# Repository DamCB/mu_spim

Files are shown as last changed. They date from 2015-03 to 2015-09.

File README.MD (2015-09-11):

# This is the mu spim project -- welcome



Mu-spim implements **light sheet microscopy** on a
smartphone camera.

_Le Mu-spim est un microscope à **feuille de lumière** pour smartphone_

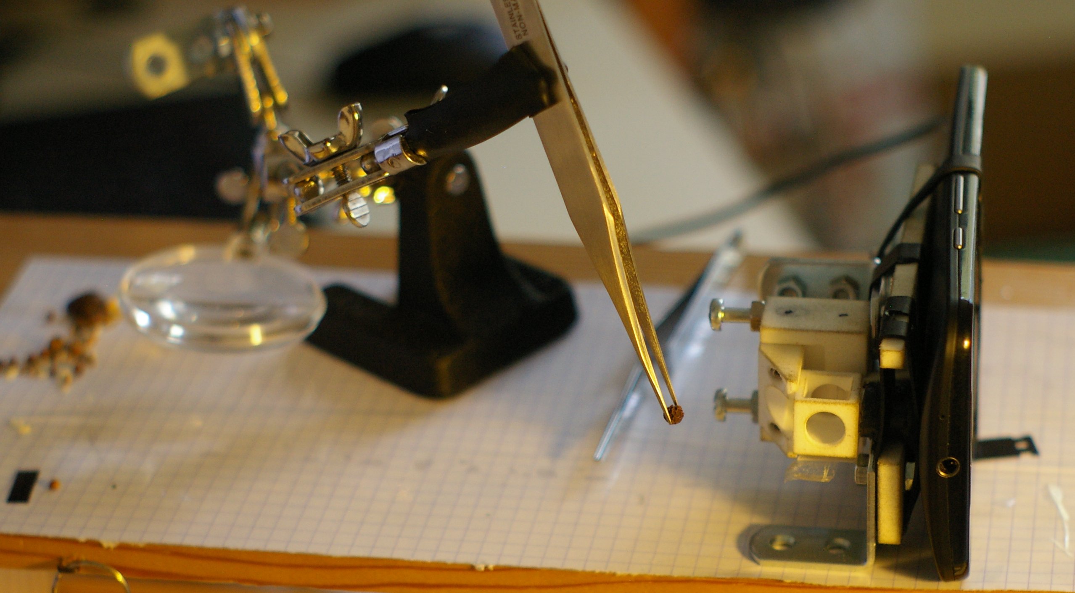
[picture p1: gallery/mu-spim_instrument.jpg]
The mu-spim v.0.1 - rubber
 

To take an image, one suspends the sample (here a grain of peper) in the small cubic room, in front of the telephone's objective.

_Pour prendre une image, on suspend l'échantillon (ici un grain de poivre) dans
la petite chambre cubique, devant l'objectif du téléphone_

The microscope uses the phone's LED flash to illuminate the sample, and a **cylindrical lens** creates a light-sheet. A section of the flat light field can be seen on the next image:

_Le microscope utilise la LED du téléphone pour illuminer un échantillon, et **une lentille cylindrique** créé une feuille de lumière. On voit ce champ lumineux par la tranche sur l'image suivante_

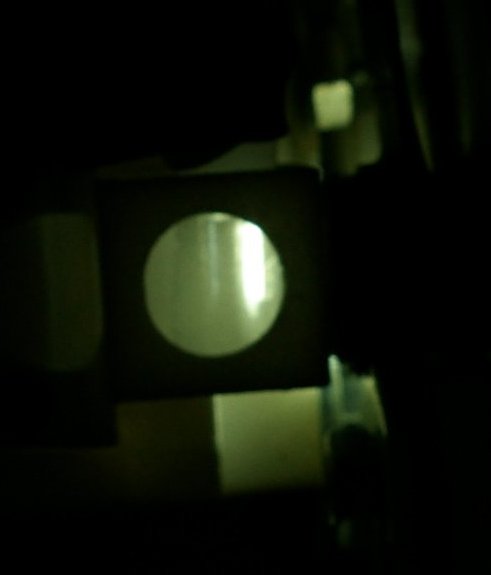
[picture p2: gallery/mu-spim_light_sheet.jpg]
The mu-spim v.0.1 - rubber


<hr/>

### La graîne de coriandre...

#### Avec la feuille de lumière (qui éclaire depuis la gauche)

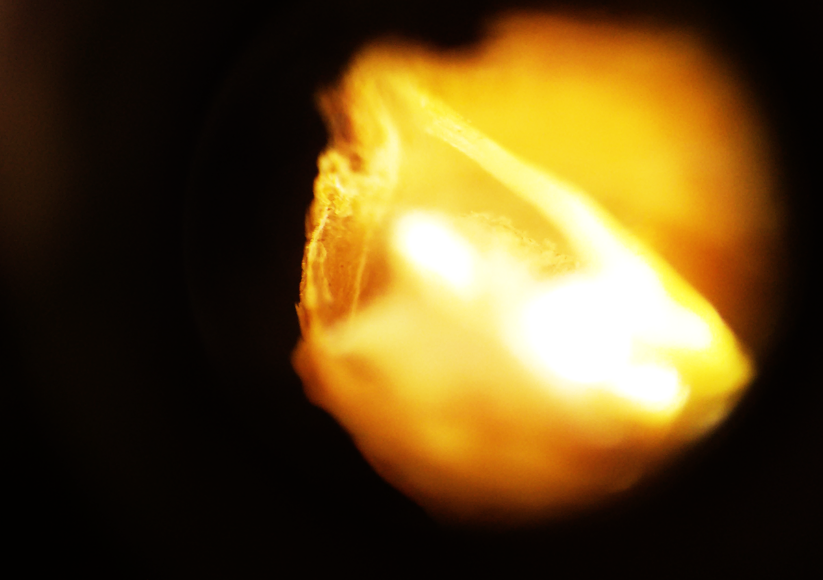
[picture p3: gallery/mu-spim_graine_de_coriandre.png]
The mu-spim v.0.1 - rubber


#### Sans la feuille de lumière

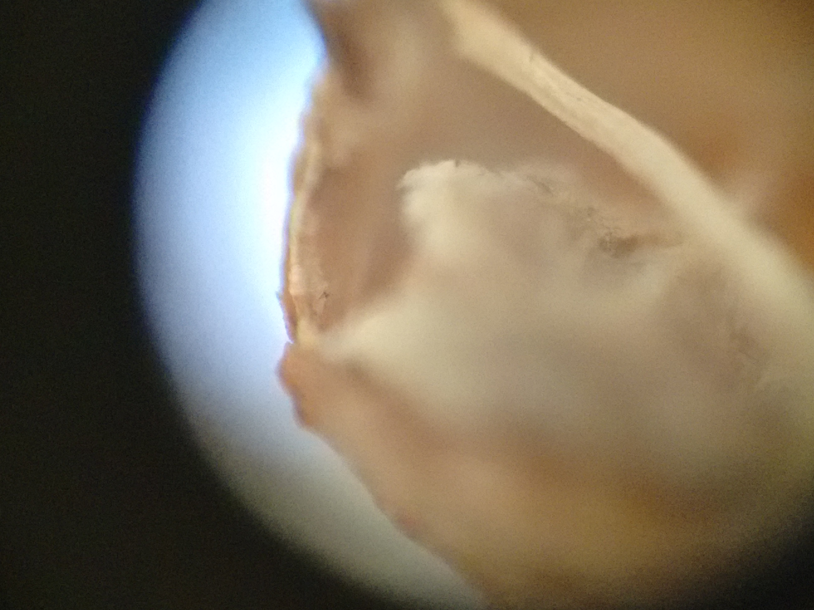
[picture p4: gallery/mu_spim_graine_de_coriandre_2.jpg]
The mu-spim v.0.1 - rubber


### Videos

<iframe src="https://player.vimeo.com/video/138321561" width="500" height="281" frameborder="0" webkitallowfullscreen mozallowfullscreen allowfullscreen></iframe> <p><a href="https://vimeo.com/138321561">Fleur s&ecirc;ch&eacute;e // Microscopy image of a flower stem. #mu-spim</a> from <a href="https://vimeo.com/user12210065">glyg</a> on <a href="https://vimeo.com">Vimeo</a>.</p>

<iframe src="https://player.vimeo.com/video/138322430" width="500" height="281" frameborder="0" webkitallowfullscreen mozallowfullscreen allowfullscreen></iframe> <p><a href="https://vimeo.com/138322430">Cardamome #mu-spim</a> from <a href="https://vimeo.com/user12210065">glyg</a> on <a href="https://vimeo.com">Vimeo</a>.</p>

> This is an early project under heavy development
>
> Guillaume Gay - http://damcb.com - guillaume@damcb.com

<br /><span xmlns:dct="http://purl.org/dc/terms/" property="dct:title">Mu-SPIM</span> de <a xmlns:cc="http://creativecommons.org/ns#" href="http://damcb.com" property="cc:attributionName" rel="cc:attributionURL">Guillaume Gay</a> est mis à disposition selon les termes de la <a rel="license" href="http://creativecommons.org/licenses/by-nc-sa/4.0/">licence Creative Commons Attribution - Pas d’Utilisation Commerciale - Partage dans les Mêmes Conditions 4.0 International</a>.<br />Fondé(e) sur une œuvre à <a xmlns:dct="http://purl.org/dc/terms/" href="https://github.com/glyg/mu_spim" rel="dct:source">https://github.com/glyg/mu_spim</a>.

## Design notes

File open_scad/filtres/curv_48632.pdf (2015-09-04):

## B-440 UV-VIS Bandpass Filter Coating Performance FOR REFERENCE ONLY

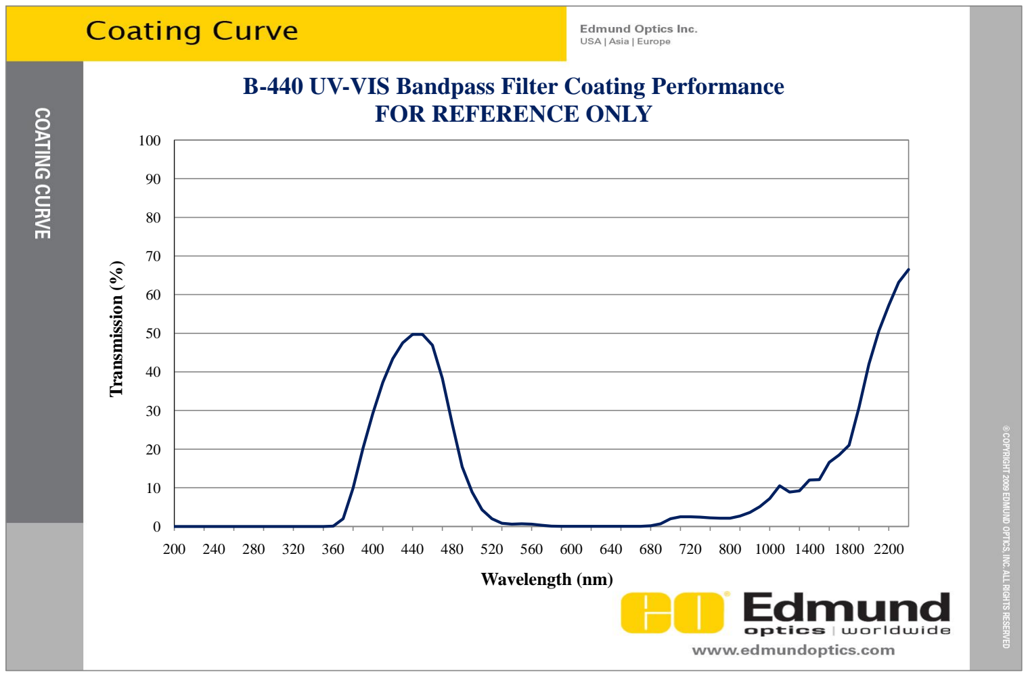
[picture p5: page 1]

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
200 | 240 | 280 | 320 | 360 | 400 | 440 | 480 | 520 | 560 | 600 | 640 | 680 | 720 | 800 1000 1400 1800 2200

### Transmission (%)

Wavelength (nm)

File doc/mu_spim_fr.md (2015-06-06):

# Mu-spim
### Un microscope 3D pour smartphone

## Introduction

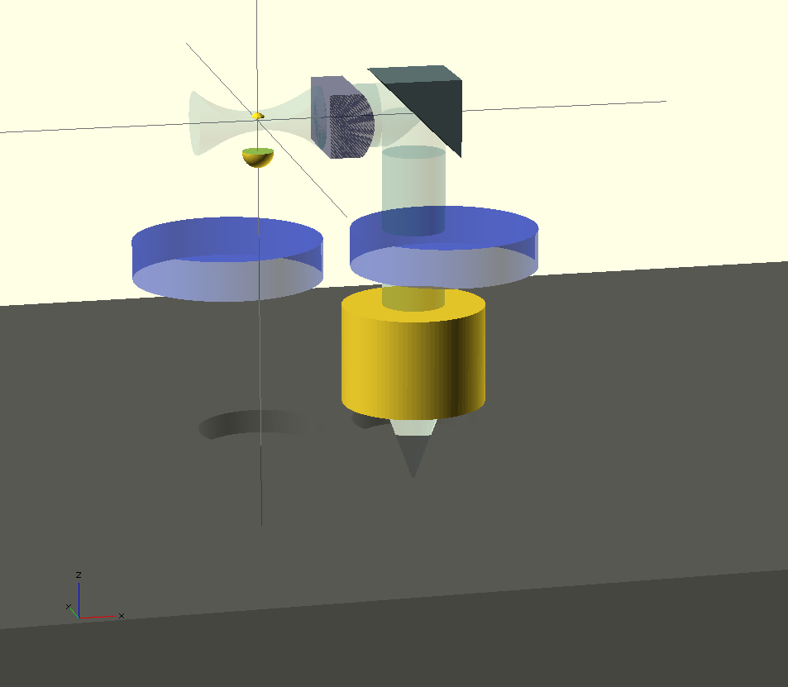
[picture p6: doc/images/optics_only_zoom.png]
Une petite feuille de lumière


Mon premier appareil photo était un petit compact Olympius, le µ-one,
offert pour mes quatorze ans. Il tenait dans la pomme de la main,
avait un zoom réglable et faisait des belles photos - sur pellicule,
au risque de trahir mon âge.

Le mu-spim aussi tient dans le creux de la main et permet de fixer le
monde qui nous entoure. L'échelle est bien différente de mon petit
appareil compact, cependant: on regarde du petit, du minuscule, plus
petit que le millimètre. Le mu-spim est un microscope portable qui
s'attache à un smartphone. En faisant tourner l'échantillon devant
l'objectif, on l'observe sous toutes ses facettes et on peut en faire
une reconstruction en trois dimensions.

Ce microscope s'inspire de deux instruments existants: le premier est
le SPIM (_Selective Plane Illumination Microscope_, microscope à plan
d'illumination sélectif), un microscope à feuille de lumière (on va y
revenir!), à destination des chercheurs en biologie. C'est un appareil
de laboratoire, équipé d'une caméra hyper-sensible et de lasers pour
éclairer les échantillons. Il y a quelques années, avec Corinne
Lorenzo et Valérie Lobjois, nous avons construit un microscope de ce
type à Toulouse. Il existe une version ouverte de ce type de
microscope: [l'OpenSPIM](http://openspim.org), que l'on peut assembler
soi même, si l'on dispose d'un bon atelier d'optique.

La deuxième source d'inspiration est le merveilleux
[Foldscope](http://foldscope.org) développé à Stanford dans le
laboratoire de Manu Parkash. C'est un petit microscope en papier, que
l'on peut tenir devant ses yeux ou devant l'objectif d'un
téléphone. Il ne coûte presque rien à fabriquer et peut être employé
dans tous les terrains, par exemple pour diagnostiquer rapidement une
infection virale dans un échantillon sanguin.

Dans la tradition du développement ouvert, le Mu-Spim est un _mix_ de
ces deux outils.

Ce projet s'adresse à deux publics, principalement:

* Les amateurs, curieux et les structures de vulgarisation
  scientifique.

* Les professionnels qui auraient besoin d'un microscope précis et
  transportable pour le diagnostic micro-biologique (bilan écologique, piscines).

##

## La microscopie à feuille de lumière

L'idée de base de ce type de microscope est de produire une _feuille
de lumière_ pour éclairer un échantillon par la tranche.

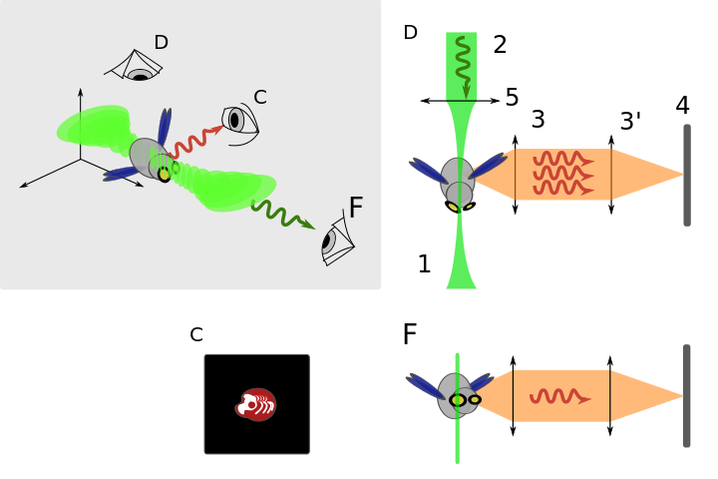
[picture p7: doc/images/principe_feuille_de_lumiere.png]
principe de la microscopie de feuille de lumière


En acquérant successivement plusieurs tranches de l'échantillon, on
parvient à reconstruire une vue en trois dimensions de ce dernier.

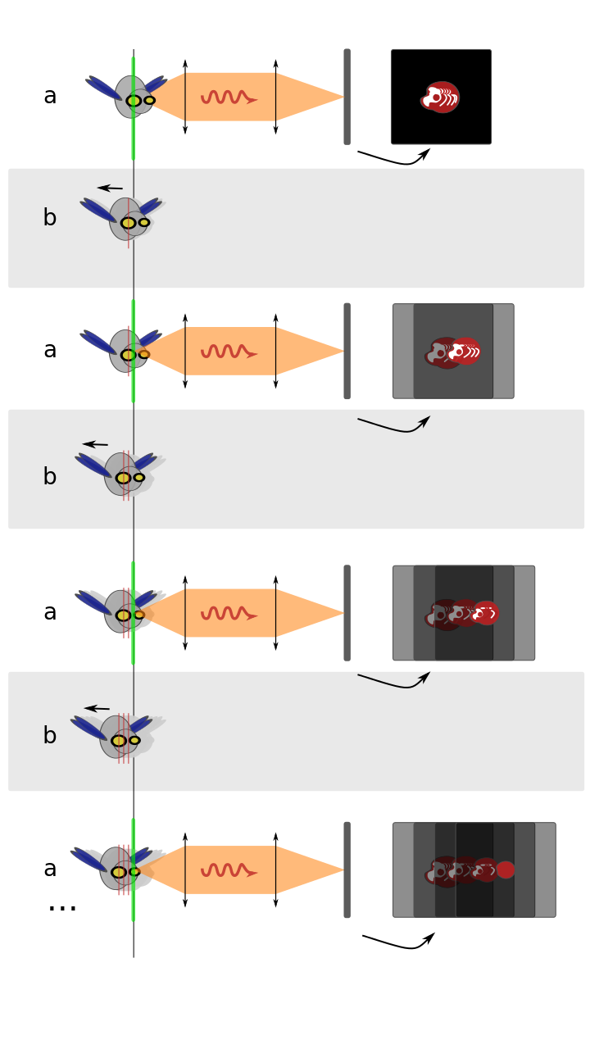
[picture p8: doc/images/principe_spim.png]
reconstruction 3D


Cette méthode de microscopie a été redécouverte par le groupe de Enrst
Stelzer au milieu des années 2000.

L'objectif est avant tout **éducatif**: rendre visible le monde
foisonnant et étrange du plus-petit-que-le-cheveu.

Ce projet s'inscrit dans une démarche **ouverte**: le code et les plans
de l'objet seront distribués sous licence libre (CC-by-SA, comme le
projet parent).

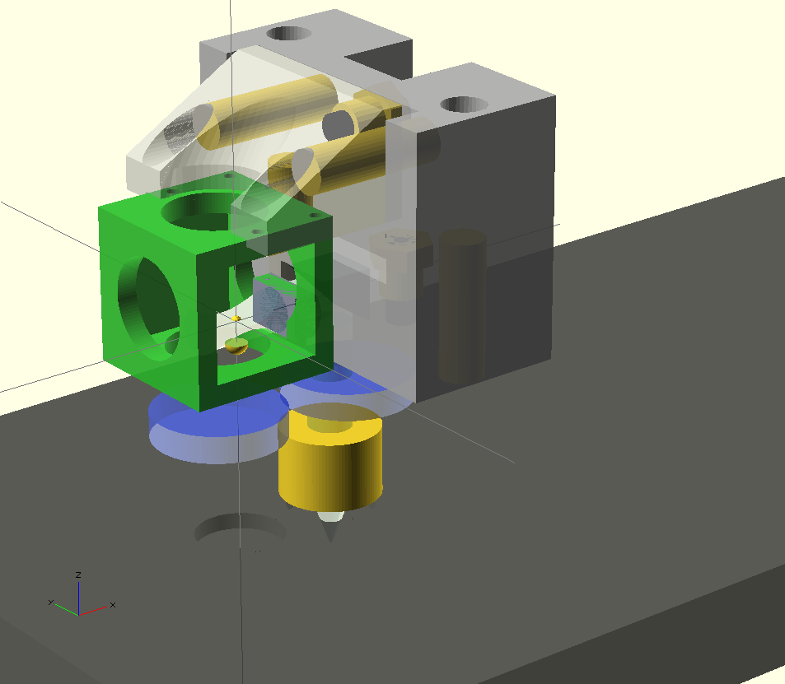
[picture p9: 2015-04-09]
doc/images/optics+chamber+top+colim.png

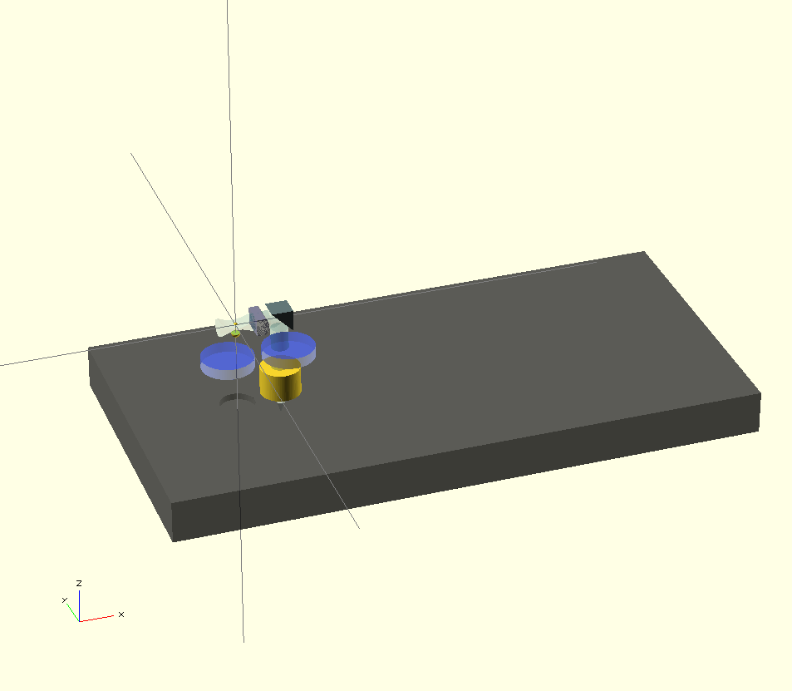
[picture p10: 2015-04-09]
doc/images/optics_only.png

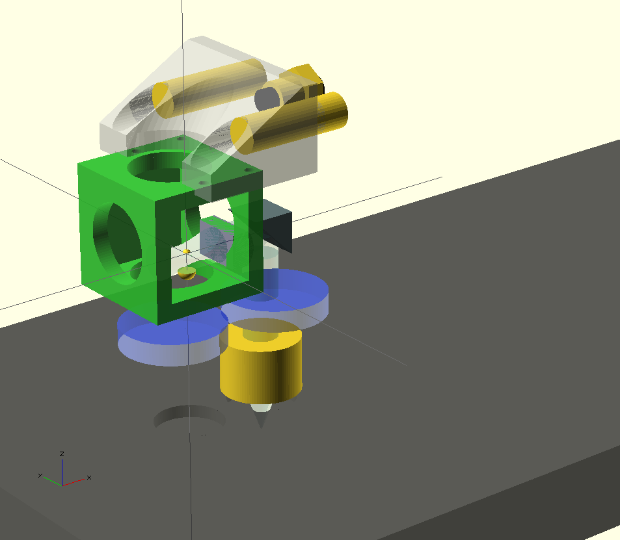
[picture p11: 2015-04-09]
doc/images/optics+chamber+top.png

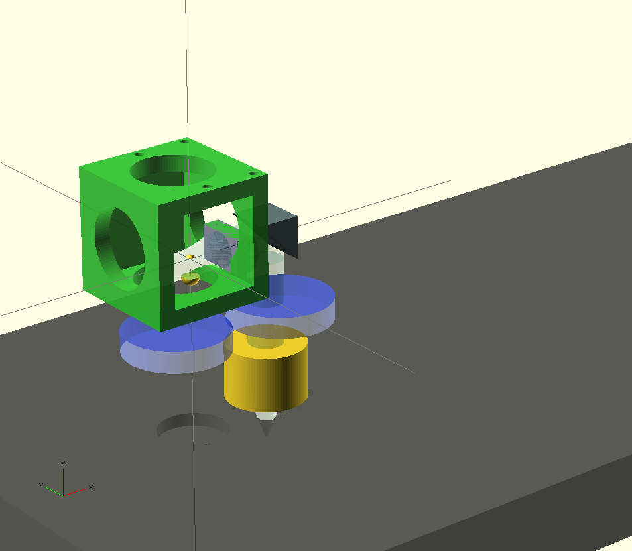
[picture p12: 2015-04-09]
doc/images/optics+chamber.png

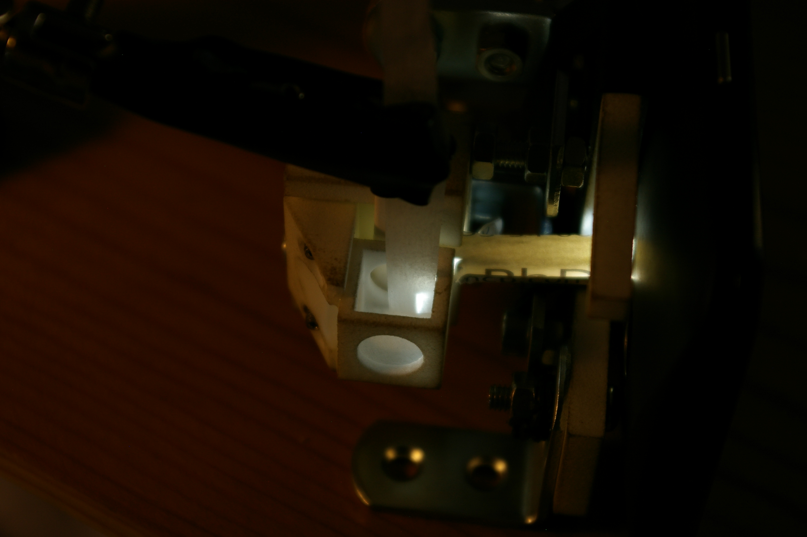
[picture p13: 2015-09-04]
doc/images/IMGP2792.JPG

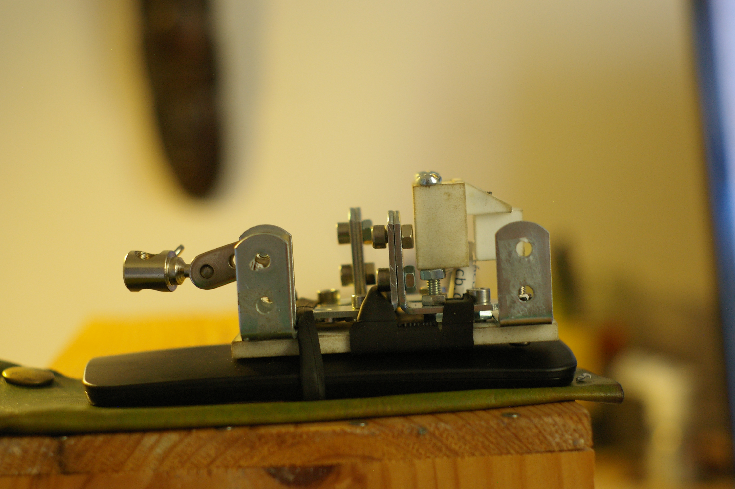
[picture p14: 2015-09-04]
doc/images/IMGP2789.JPG

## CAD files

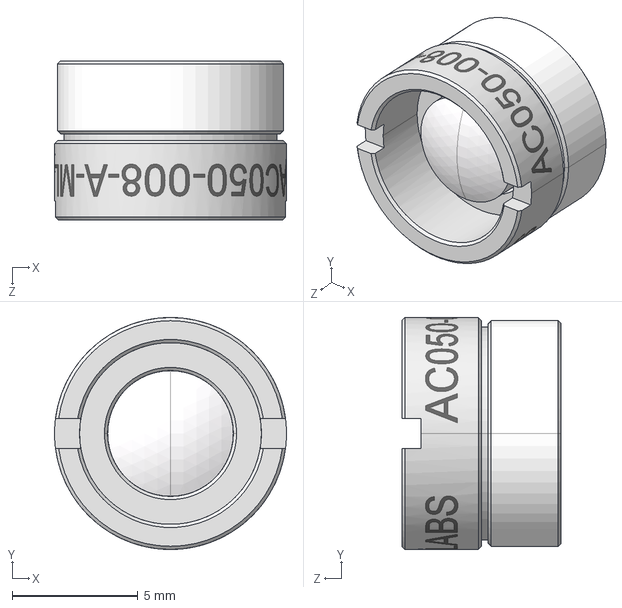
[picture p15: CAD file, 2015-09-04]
open_scad/parts/AC050-008-A-ML-Step.step
9.24 x 9.24 x 6.35 mm

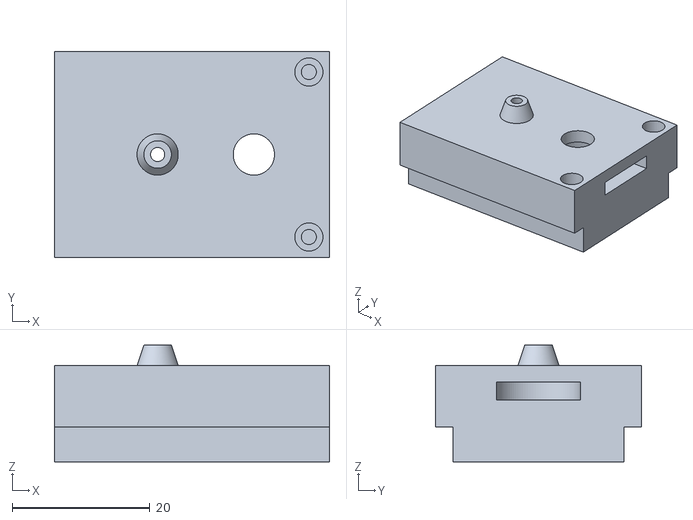
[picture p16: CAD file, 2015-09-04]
stl/base_block.stl
40.0 x 30.0 x 17.0

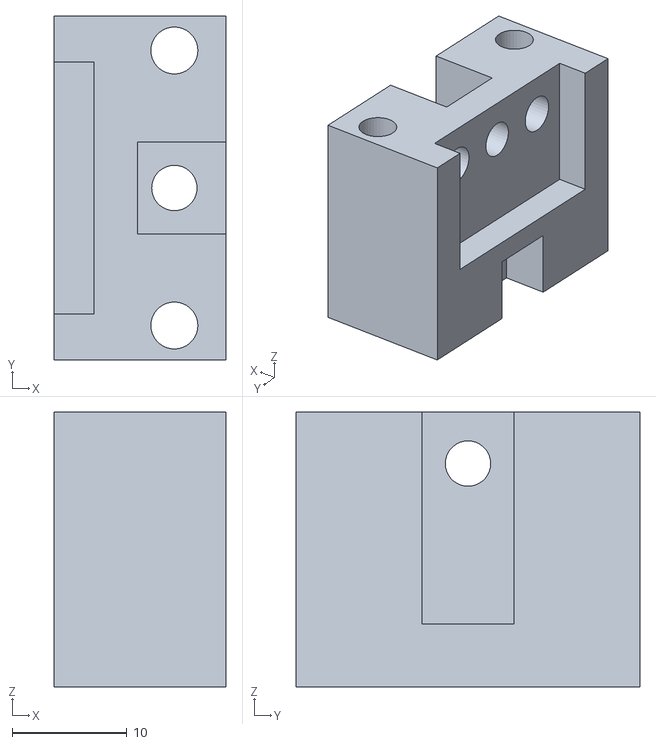
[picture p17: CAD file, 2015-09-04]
stl/collimation_block.stl
15.0 x 30.0 x 24.0

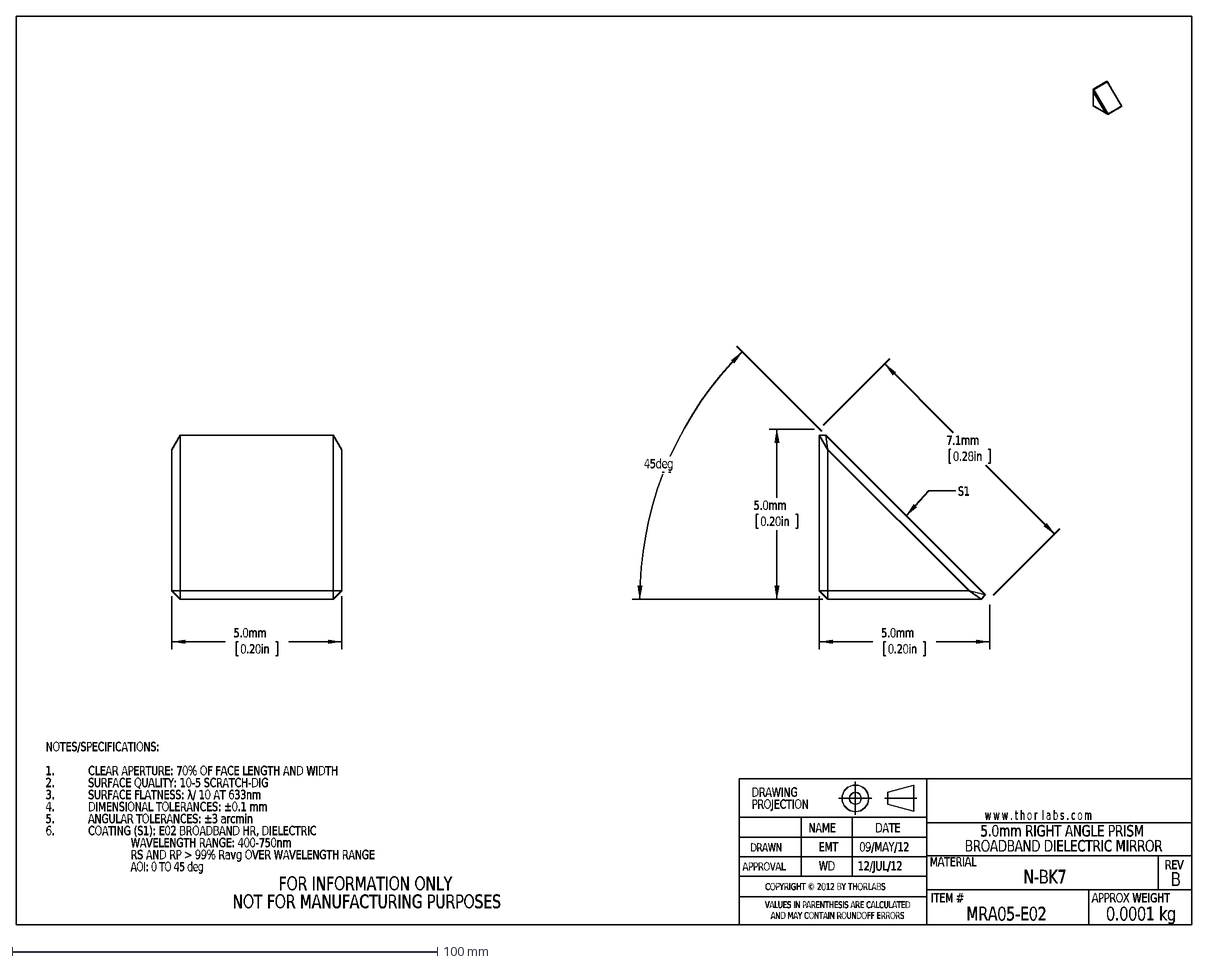
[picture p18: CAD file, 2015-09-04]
open_scad/parts/MRA05-E02-AutoCADDXF.dxf
NOTES/SPECIFICATIONS:
CLEAR APERTURE: 70% OF FACE LENGTH AND WIDTH
1.
SURFACE QUALITY: 10-5 SCRATCH-DIG
2.
SURFACE FLATNESS: λ/ 10 AT 633nm
3.
DIMENSIONAL TOLERANCES: ±0.1 mm
4.
ANGULAR TOLERANCES: ±3 arcmin
5.
COATING (S1): E02 BROADBAND HR, DIELECTRIC
6.
WAVELENGTH RANGE: 400-750nm
RS AND RP > 99% Ravg OVER WAVELENGTH RANGE
AOI: 0 TO 45 deg
B
MRA05-E02
MATERIAL
DRAWN
APPROVAL
REV
EMT
09/MAY/12
DATE
w w w . t h o r l a b s . c o m
ITEM #
APPROX WEIGHT
N-BK7
0.0001 kg
VALUES IN PARENTHESIS ARE CALCULATED
AND MAY CONTAIN ROUNDOFF ERRORS
DRAWING
PROJECTION
NAME
FOR INFORMATION ONLY
NOT FOR MANUFACTURING PURPOSES
5.0mm RIGHT ANGLE PRISM
BROADBAND DIELECTRIC MIRROR
COPYRIGHT © 2012 BY THORLABS
WD
12/JUL/12
5.0mm
0.20in
7.1mm
0.28in
45deg
S1

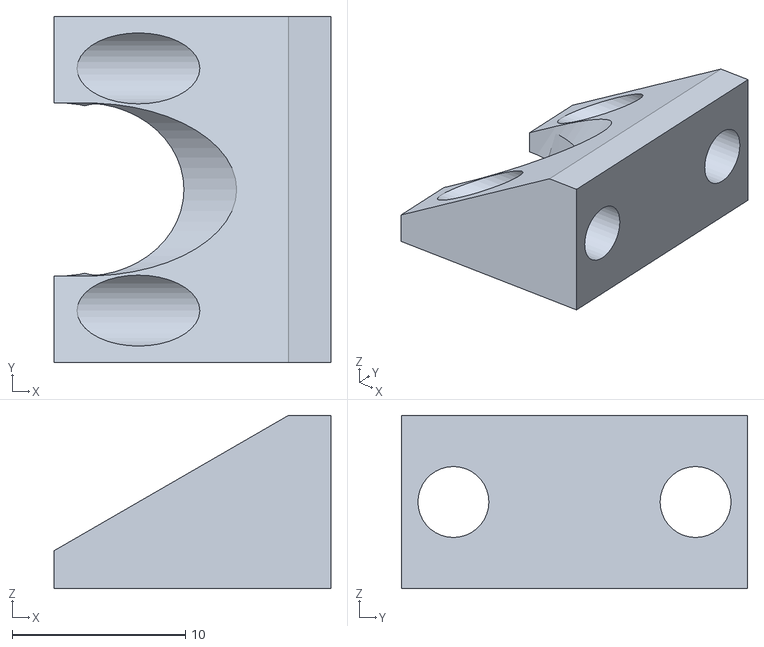
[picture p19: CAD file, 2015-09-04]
stl/chamber_top.stl
16.0 x 20.0 x 10.0

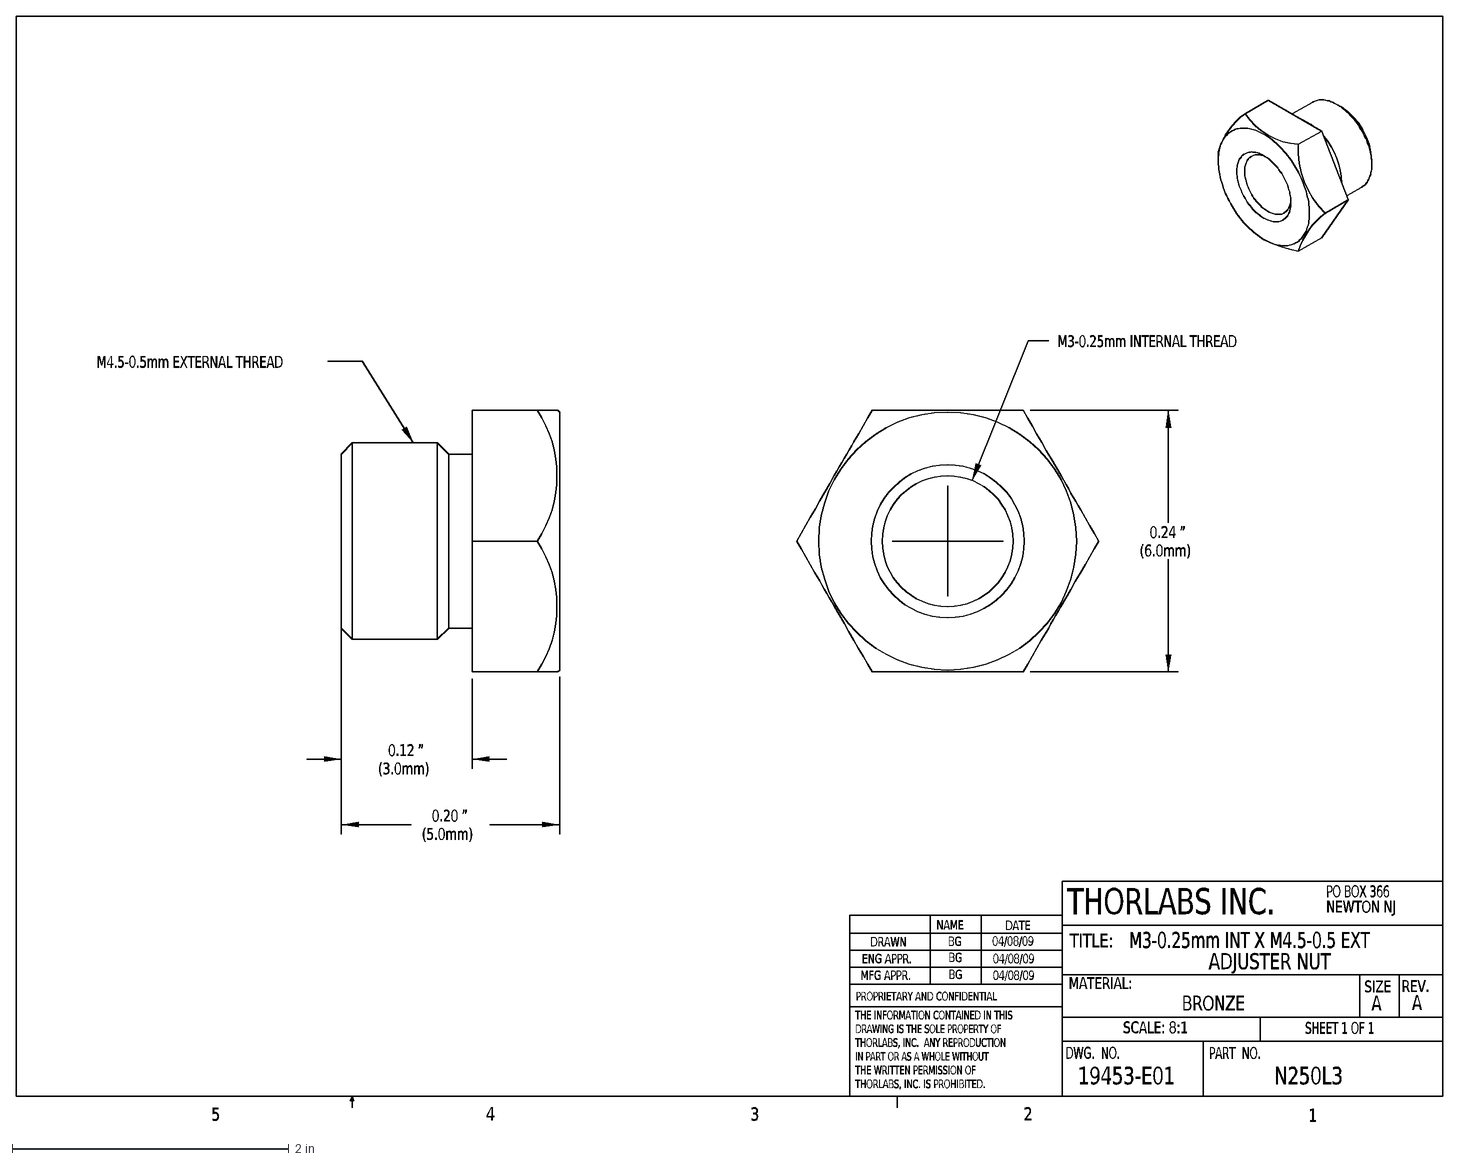
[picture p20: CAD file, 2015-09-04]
open_scad/parts/N250L3P-AutoCADDXF.dxf
A
5
4
3
2
1
N250L3
MATERIAL:
PART NO.
PROPRIETARY AND CONFIDENTIAL
DRAWN
ENG APPR.
MFG APPR.
NAME
TITLE:
SIZE
REV.
SCALE: 8:1
SHEET 1 OF 1
19453-E01
THE INFORMATION CONTAINED IN THIS
DRAWING IS THE SOLE PROPERTY OF
THORLABS, INC. ANY REPRODUCTION
IN PART OR AS A WHOLE WITHOUT
THE WRITTEN PERMISSION OF
THORLABS, INC. IS PROHIBITED.
DWG. NO.
BG
04/08/09
DATE
THORLABS INC.
PO BOX 366
NEWTON NJ
M3-0.25mm INT X M4.5-0.5 EXT
ADJUSTER NUT
BRONZE
0.24
”
(6.0mm)
M3-0.25mm INTERNAL THREAD
0.20
(5.0mm)
0.12
(3.0mm)
M4.5-0.5mm EXTERNAL THREAD

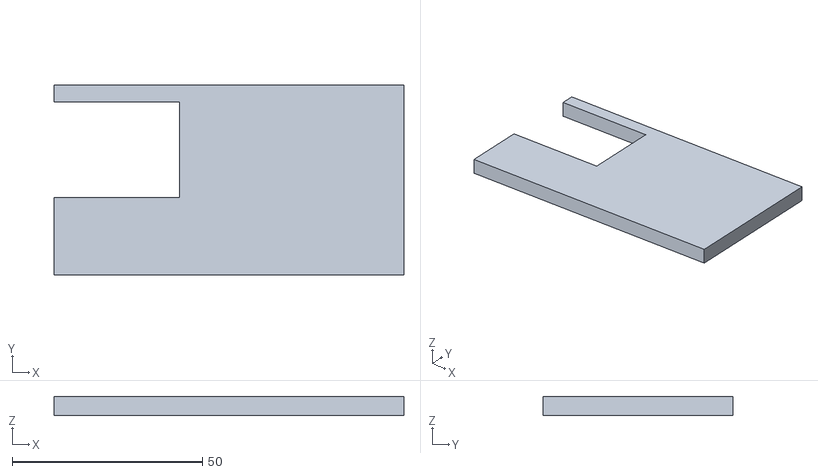
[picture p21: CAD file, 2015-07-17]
stl/optics_plate.stl
92.0 x 50.0 x 5.00

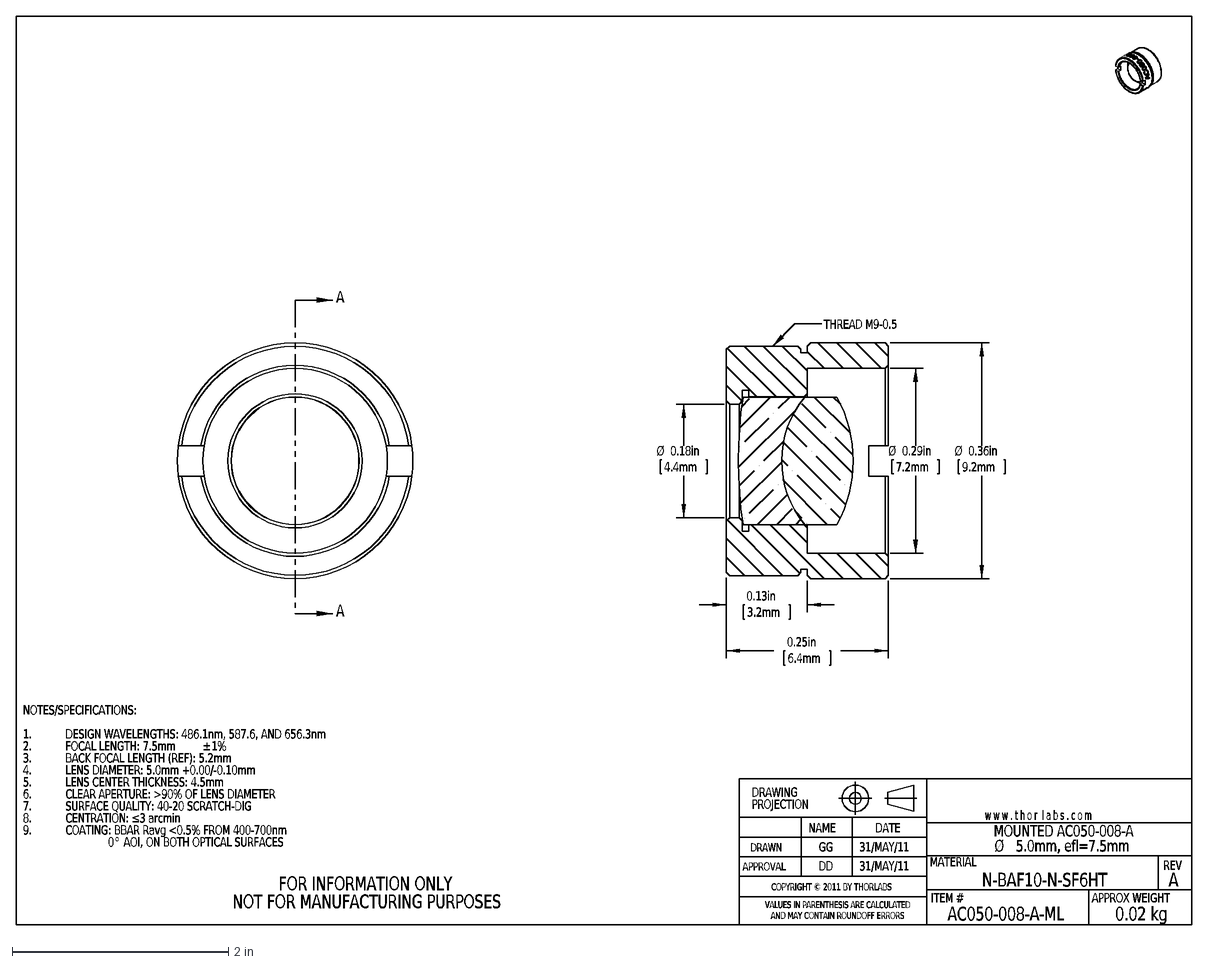
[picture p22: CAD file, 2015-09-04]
open_scad/parts/AC050-008-A-ML-AutoCADDXF.dxf
NOTES/SPECIFICATIONS:
DESIGN WAVELENGTHS: 486.1nm, 587.6, AND 656.3nm
1.
FOCAL LENGTH: 7.5mm
±
1%
2.
BACK FOCAL LENGTH (REF): 5.2mm
3.
LENS DIAMETER: 5.0mm +0.00/-0.10mm
4.
LENS CENTER THICKNESS: 4.5mm
5.
CLEAR APERTURE: >90% OF LENS DIAMETER
6.
SURFACE QUALITY: 40-20 SCRATCH-DIG
7.
CENTRATION: ≤3 arcmin
8.
COATING: BBAR Ravg <0.5% FROM 400-700nm
9.
0
°
AOI, ON BOTH OPTICAL SURFACES
A
AC050-008-A-ML
MATERIAL
DRAWN
APPROVAL
REV
GG
DD
31/MAY/11
DATE
w w w . t h o r l a b s . c o m
ITEM #
APPROX WEIGHT
N-BAF10-N-SF6HT
0.02 kg
VALUES IN PARENTHESIS ARE CALCULATED
AND MAY CONTAIN ROUNDOFF ERRORS
DRAWING
PROJECTION
NAME
FOR INFORMATION ONLY
NOT FOR MANUFACTURING PURPOSES
COPYRIGHT © 2011 BY THORLABS
MOUNTED AC050-008-A
Ø
5.0mm, efl=7.5mm
0.36in
9.2mm
0.25in
6.4mm
0.13in
3.2mm
0.18in
4.4mm
0.29in
7.2mm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

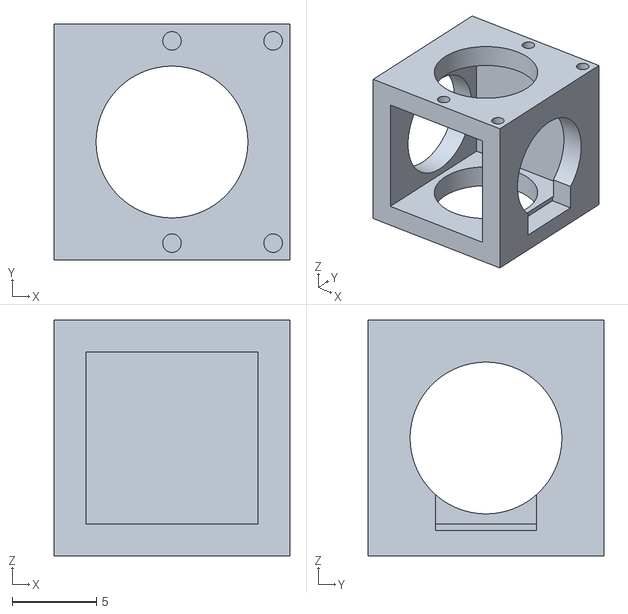
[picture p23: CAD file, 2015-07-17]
stl/chamber.stl
14.0 x 14.0 x 14.0

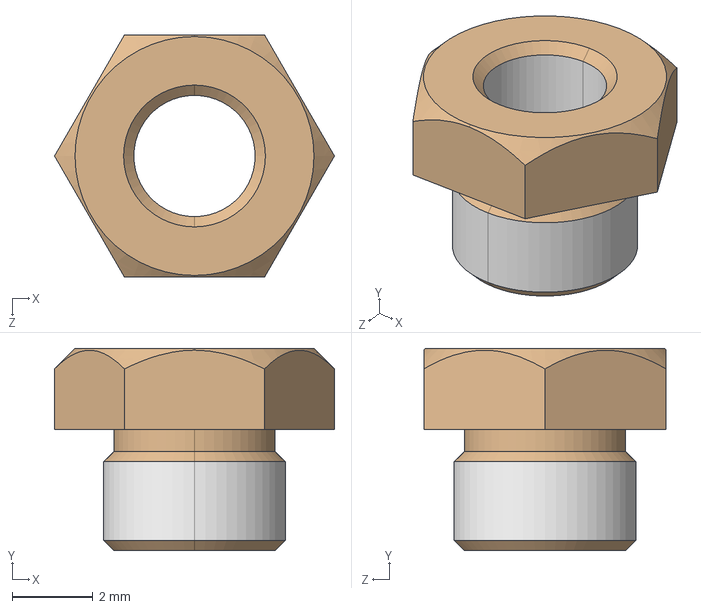
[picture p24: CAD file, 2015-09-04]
open_scad/parts/N250L3P-Step.step
6.93 x 5.00 x 6.00 mm

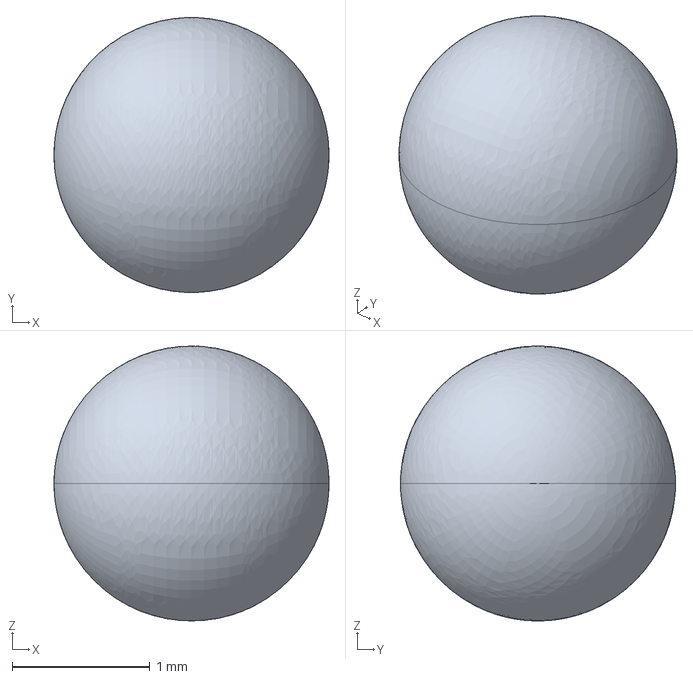
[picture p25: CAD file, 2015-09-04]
open_scad/parts/iges_32744.igs
2.00 x 2.00 x 2.00 mm

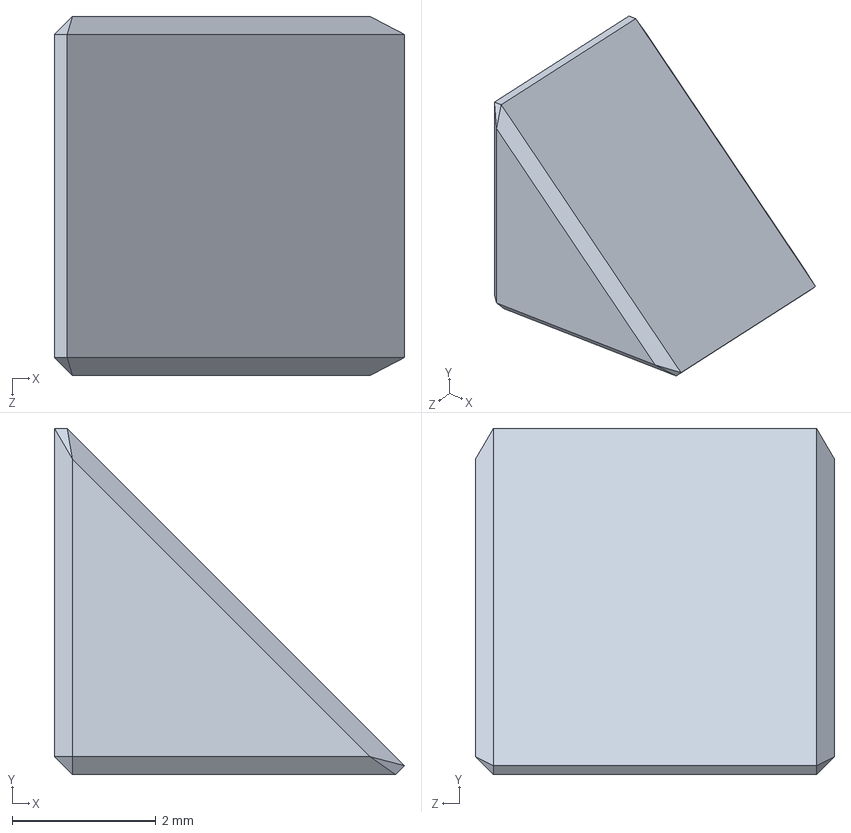
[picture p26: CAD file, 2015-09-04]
open_scad/parts/MRA05-E02-Step.step
4.88 x 4.82 x 5.00 mm

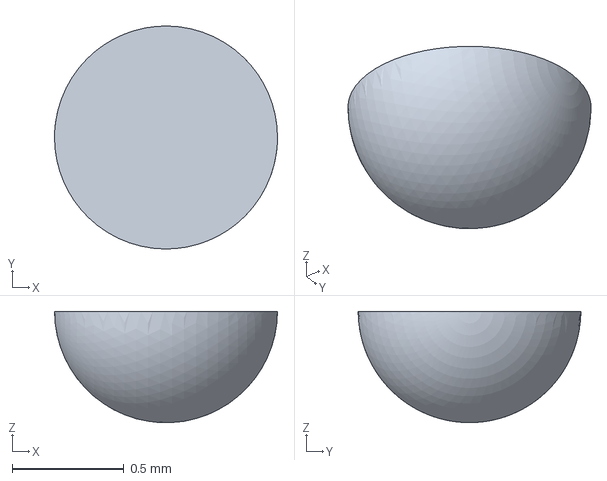
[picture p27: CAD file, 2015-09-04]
open_scad/parts/step_49568.stp
1.00 x 1 x 0.499 mm

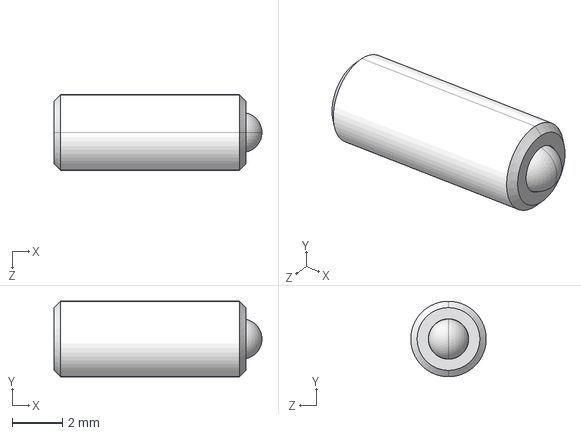
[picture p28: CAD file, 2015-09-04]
open_scad/parts/F3SS8-Step.step
8.25 x 3.00 x 3.00 mm

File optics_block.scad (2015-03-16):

use <chamber.scad>;
use <excitation_optics.scad>;
use <collection_optics.scad>;

use <libraries/thread.scad>;


module hex_adjustment_screw
(
    //THORLABS P/N F3SS8
)
{
    color([0, 0, 0])
    union()
    {
	difference()
	{
	    metric_thread(3, 0.25, 7.6);
	    translate([0, 0, -0.1]) cylinder(r=0.75, h=2.1, $fn=6);
	}
	translate([0, 0, 7.]) sphere(d=1.5, $fn=100);
    }
}

module adjuster_nut
(
    //THORLABS P/N N250L3
)
{
    difference()
    {
	union()
	{
	    cylinder(r=3, h=2, $fn=6);
	    translate([0, 0, 2]) metric_thread(4.5, 0.5, 3);
	}
	translate([0, 0, -1]) metric_thread(3, 0.25, 7.6, internal=true);
    }
}

module adjuster
(
    nut_shift=1.2
)
{
    translate([0, 0, -8])
    {
	hex_adjustment_screw();
	translate([0, 0, nut_shift]) adjuster_nut();
    }
}

module x_excitation_adjuster
(
    adjuster_tip = [10, 0, 15]
)
{
    translate(adjuster_tip)
    rotate([0, -90, 0])
    adjuster();
}

module y_excitation_adjuster
(
    adjuster_tip = [18, 0, -5]
)
{
    translate(adjuster_tip)
    rotate([0, 180, 0])
    adjuster(nut_shift=-0.);
}


module x_excitation_rods
(
    interaxial_dist = 12,
    position=[15, 0, 15],
)
{
    translate(position)
    {
	translate([0, -interaxial_dist/2, 0])
	rotate([0, -90, 0])
	cylinder(r=2, h=12.7, $fn=36);//THORLABS P/N SR05
	translate([0, interaxial_dist/2, 0])
	rotate([0, -90, 0])
	cylinder(r=2, h=12.7, $fn=36);//THORLABS P/N SR05
    }
}

module y_excitation_rods
(
    interaxial_dist = 22,
    position=[15, 0, -5],
)
{
    translate(position)
    {
	translate([0, -interaxial_dist/2, 0])
	cylinder(r=2, h=12.7, $fn=36);//THORLABS P/N SR0.5
	translate([0, interaxial_dist/2, 0])
	cylinder(r=2, h=12.7, $fn=36);//THORLABS P/N SR0.5
    }
}

module collimation_block
(
    position=[15, 0, 3.5],
    exc_axis_x=10,
)
{
    translate(position)
    {
	difference()
	{
	    translate([0, 0, 4]) cube([15, 30, 24], center=true);
	    union()
	    translate(-position)
	    {
		translate([exc_axis_x-1.8, 0, -4.51])
		cube([6.1*1.42, 5.1*1.42, 10*1.42], center=true);
		translate([exc_axis_x-3, 0, 15]) cube([8, 19, 20], center=true);
		xy_excitation_holes();
	    }
	}
    }
}

module xy_excitation_holes
(
    x_tip=[10, 0, 15],
    y_tip = [18, 0, -5],
)
{
    // x axis
    x_excitation_rods();
    translate([12, 0, 0]) x_excitation_rods();
    // y axis
    y_excitation_rods();
    translate([0, 0, 12])
    y_excitation_rods();
    translate(y_tip+[0, 0, 8]) rotate([0, 180, 0])
    union()
    {
	translate([0, 0, -18])
	//cylinder(r=4, h=20, $fn=60);
	translate([-4.8, -4, 0])
	cube([8, 8, 20], center=True);
	translate([0, 0, 1.8])
	metric_thread(4.5, 0.5, 6.2, internal=true);
    }
    translate(x_tip+[6.2, 0, 0])
    rotate([0, -90, 0])
    metric_thread(4.5, 0.5, 6.2, internal=true);

}

chamber_cube_outer=14;
chamber_center=[-2., 0, 3.5];
magnets_center = chamber_center + [3, 0, chamber_cube_outer/2];


module chamber_top
(
    position=[0, 0, 0]
)
{
    translate(position)
    difference()
    {
	translate([-7, 0, 0]) cube([14, 18, 10], center=true);
	union()
	{
	    //offset(0.1)
	    x_excitation_rods(position=[-2, 0, 0]);
	    x_excitation_rods(position=[2, 0, 0]);
	    translate([-12, 0, -5]) cylinder(r=5, h=3, $fn=50);
	    translate([-15, 0, -5]) rotate([0, 30, 0])
	    union()
	    {
		cylinder(r1=5, r2=5, h=20, $fn=50);
		translate([-5, 0, 10])
		cube([10, 10, 20], center=true);
	    }
	    translate([-8, 0, 5]) rotate([0, -30, 0])
	    cube([20, 20, 6], center=true);
	    translate([-9, 0, 1.2]) rotate([0, -60, 0])
	    cube([2, 10, 2], center=true);
	    translate(magnets_center - position )//magnets_center)//+[0, 0, -1.1])
	    four_magnet_holes(inter_axial_x=6,
		inter_axial_y=12);
	    translate(chamber_center - position - [-5, 0, 0])
	    cube(chamber_cube_outer+0.2, center=true);
	}
    }
}


module base_block
(
    position=[5, 0, -5],
    filter_thick=2.5+0.1,
    cube_h=14.,
    exc_axis_x=10,
    //position=[0, 0, 0]
)
{
    translate(position)
    union()
    {
	difference()
	{
	    translate([0, 0, -cube_h/2])
	    cube([35, 30, cube_h], center=true);
	    union()
	    {
		filter_slot(filter_center=[2+exc_axis_x, 0, -10.] - position);
		rotate([0, 0, 180]) translate([2, 0, -10.] - position)  filter_slot();
		//excitation clearing
		translate([exc_axis_x, 0, -20] - position) cylinder(r=3, h=30, $fn=100);
		//collection clearing
		translate([0, 0, -20] - position)
		cylinder(r=5, h=14, $fn=100);
		translate([0, 0, -8] - position)
		cylinder(r=1.5, h=5, $fn=100);
		translate([exc_axis_x, 0, -22] - position)
		metric_thread(9, 0.5, 10, internal=true);
		// four_magnet_holes(inter_axial_x=6,
		// 	inter_axial_y=12);
	    }
	}
	translate(-position)
	%lens_holder();
    }
}

module lens_holder
(
    lens_BFL=2,
    lens_dia=2,
    position=[4, 0, 0],
    cube_h=2.5,
    cone_h=3,
)
{
    translate(position)
    union()
    translate(-position)
    translate([0, 0, -lens_BFL-cone_h])
    difference()
    {
	cylinder(r1=3., r2=2., h=cone_h, $fn=100);
	translate([0, 0, -0.05])
	cylinder(r1=1.5, r2=1.02, h=cone_h+0.1, $fn=100);
    }
}



module filter_slot
(
    filter_thick=2.5,
    filter_center=[7, 0, 0],
    filter_dia=12,
    tol=0.15,
)
{

    translate(filter_center)
    union()
    {
	translate([0, -(filter_dia+tol)/2, 0])
	cube([filter_dia+tol, filter_dia+tol, filter_thick+tol], center=false);
	cylinder(r=(filter_dia+tol)/2, h=filter_thick+tol, $fn=100);
    }
}
//whole_chamber(chamber_center=chamber_center, outer=chamber_cube_outer);

x_adjust_contact = [10, 0, 15];
x_excitation_adjuster(adjuster_tip=x_adjust_contact);

// translate([4, 0, 0])
// x_excitation_rods(position=x_adjust_contact);

// Imaging optics
im_lens_BFL=2;
//imaging_lens(back_focal_length=im_lens_BFL);

y_excitation_rods();
x_excitation_rods();
y_excitation_adjuster();

//chamber_top(position=x_adjust_contact);
base_block();
%collimation_block();
//xy_excitation_holes();

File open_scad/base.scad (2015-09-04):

use <phone.scad>;
include <base_dimensions.scad>;


module dt12xy
(
    //thorlabs P/N DT12XY/M
    position=[60, -20, 8]
)
{
    translate(position)
    {
	union()
	{
	    rotate([0, 90, 0]) translate([-5, 0, 13]) dt12xy_ajust();
	    rotate([90, 0, 0]) translate([0, -5, 13]) dt12xy_ajust();
	    cube([25.4, 25.4, 30], center=true);
	}
	rotate([0, 0, 90])
	dt12b_m();
	rotate([180, 0, 0])
	dt12b_m();
    }
}


module dt12xy_ajust
(
)
{
    union()
    {
	cylinder(r=4, h=20, $fn=60);
	translate([0, 0, 10]) cylinder(r=5, h=10, $fn=60);
	translate([0, 0, 9]) cylinder(r1=4, r2=5, h=1, $fn=60);
    }
}

module dt12b_m
(
    //thorlabs P/N DT12B/M
    position=[0, 0, 14.7+3.]
)
{
    translate(position)
    difference()
    {
	cube([43, 25.4, 8], center=true);
	union()
	{
	    translate([0, 0, -3.5])
	    {
		cube([25.5, 25.5, 2], center=true);
		cylinder(r1=3, r2=3, h=20, $fn=60);
	    }
	    translate([0, 0, -3.2])
	    cylinder(r1=10, r2=3., h=2.4, $fn=60);
	}
    }
}


module optics_plate
(
    position=[36, -8, -19]
)
{
    translate(position)
    translate([0, 0, 2.5])
    difference()
    {
	      cube([92, 50, 5], center=true);
        union()
	      {
	          translate([5.05-position[0], -position[1], 0])
	          {
              cube([36, 25.1, 5.1], center=true);
              union()
              {
                translate([])
                %cylinder(r1=5.1, r2=4.1);
              }
            }
	      }
    }
}

module backplate
(
    position=[60, -20, 30]
)
{
    translate(position)
    cube([50, 50, 10], center=true);
}


// module foot
// (

// )

module rail
(
    entraxe=10,
    dia=3,
    length=100,
)
{
    ax_shift=entraxe/2;
    rad = dia/2;
    union()
    {
	translate([-ax_shift, 0, 0])
	cylinder(r=rad, h=length,
	    center=true, $fn=12);
	translate([ax_shift, 0, 0])
	cylinder(r=rad, h=length,
	    center=true, $fn=12);
    }
}


module xy_rails
(
    position=[130, 30, -20],
    x_shift=-70,
    x_length=200,
    y_shift=-30,
    y_length=100,
    entraxe=10
)
{
    translate(position) translate([0, 0, -entraxe*0.75])
    {
	// x axis
	translate([x_shift, 0, entraxe/2])
	rotate([0, 90, 0])
	rail(length=x_length);
	// y axis
	translate([0, y_shift, 0])
	rotate([0, 90, 0]) rotate([90, 0, 0])
	rail(length=y_length);
    }
}



module crux
(
        position=[130, 40, -20],
)
{
    translate(position)
    {
	xy_rails(position=[0, 0, 0]);
	difference()
	{
	    translate([-10, 0, -5])
	    cube([30, 30, 25], center=true);
	    union()
	    {
		xy_rails(position=[0, 0, 0]);
		translate([-24, -12, -5])// rotate([90, 0, 0])
		sphere(r=8, center=true);
		translate([-24, -19, -5]) rotate([90, 0, 0])
		cylinder(r=8, h=20, center=true);
	    }
	}
    }
}




module phone_stand
(
    angle = -45,
)
{


}

dt12xy();
optics_plate();
phone();
backplate();
phone_stand();

crux();

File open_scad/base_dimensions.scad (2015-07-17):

focal_point = [0, 0, 0];

excitation_source = [14, 0, -24]; //estimated
exc_axis_x = excitation_source[0];

// collimation block position

x_adjust_contact = [exc_axis_x, 0, 15];
y_adjust_contact = [exc_axis_x+8, 0, -5];

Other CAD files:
open_scad/parts/F3SS8-AutoCADDXF.dxf
open_scad/parts/step_45933.stp
open_scad/parts/LJ1918L1-A-Step.step
open_scad/parts/LJ1918L1-A-AutoCADDXF.dxf
open_scad/chamber.scad
open_scad/collection_optics.scad
open_scad/excitation_optics.scad
open_scad/light_path.scad
open_scad/mu_spim.scad
open_scad/optic_blocks.scad
open_scad/phone.scad
open_scad/sample_holder.scad
open_scad/stl_optics_plate.scad
open_scad/stl_parts.scad

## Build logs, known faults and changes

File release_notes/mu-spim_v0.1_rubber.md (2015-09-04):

### Mu Spim v 0.1 codename rubber // caoutchouc

What's new:
-----------
- Light sheet
- Self-sustained structure
- "Functional" mu-spim

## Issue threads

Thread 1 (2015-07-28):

design modifications

glyg, 2015-07-28:
- `collimation_block`
  - [ ] Increase space for the x and y adjuster nobs - making it easier to insert the bolts. Set to 16 mm
  - [ ]  redesign thoroughly (rails?)
  - [ ]  design 'collimation' tube
- `optics_plate`
  - [ ] increase thickness
  - [ ] make symetrical. I think overall dims should be about (40, 40, 4)
  - [ ]  redesign thoroughly (rails?)
- `base_block`
  - [ ] redesign thoroughly (rails?) / optics plates
  - [ ] that set of optics should suffice
    http://www.thorlabs.de/newgrouppage9.cfm?objectgroup_id=3810
- `chamber` and `chamber_top`
  - [ ] move cyl. lens holder to chamber top
  - [ ] make cyl holder fully closed and thicker

glyg, 2015-07-28:
Change the imaging lens:
Thorlabs mounted aspherical lenses could be interesting, for example:

http://www.thorlabs.de/thorcat/20300/C390TME-A-AutoCADPDF.pdf

glyg, 2015-09-11:
Actually, look at al this list:

http://www.thorlabs.de/newgrouppage9.cfm?objectgroup_id=3810

Might be fun buying 3 or 4 of those..

Closed 2021-05-12.

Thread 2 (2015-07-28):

mu-spim + smartphone holder

glyg, 2015-07-28:
finish design

glyg, 2015-09-04:
solved by the power of rubber

Closed 2015-09-04.

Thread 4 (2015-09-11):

Optical aspects to investigate

glyg, 2015-09-11:
These aspects will only be investigated once the numerous points of issue #1 are fixed, nevertheless, some planning can already be made. Feel free to pitch in.

To fix the ideas the current collection lens has a focal length of 7.5 mm. The effective magnification has yet to be measured correctly, but a ball park estimates gives a 15X 'classical' magnification (that is the magnification given for a 250 mm tube length). Here the tube lens is played by the phone camera. EXIF metadata indicates a focal length of 3.5 mm, the whole tube length must be about 10 mm, and the objective is 7.5 mm. So this is around a 1.5X strictly speeking (closer to macro). This low magnification is compensated by the small size of the detection chip (for which I don't have specs), about 7mm. Filed of view is about 3 mm in diameter, with 2.5 "usefull" mm.

There is room for filters in the excitation arm (for e.g. structured illumination) and in the collection arm.

By design, those aspects have to be reconsidered:
- The light source is not coherent but there is a blue peak in the led spectrum at 450 nm with 50 nm FWHM. This is very broad, but I assume it will be enough to excite some fluorophores. For now I only dispose of a high pass low pass filter pair. The absence of interference pattern might be interesting also, maybe the excitation field density in the sample will differ w/r to laser based excitation?
- Light sheet optimization: I don't think we can achieve diffraction limited thickness. This is why SI strategies are interesting.
- Because linear polarizers are cheap, I would like to investigate polarized light sheet,
  with cross-polarized detection (has anybody done this?). This should provide the same rejection of diffracted light, while  conserving the full excitation / collection spectrum (I'm thinking at those beautiful images of small ponds/swamps micro-organisms).
- I'm not sure whether DIC is achievable (with an added source in front of the detection lens).
### Instrumental aspects
#### Sample holder

Bernard Ducommun already very kindly proposed to investigate the sample holder aspects, as he is a specialist of the matter ([see what he does!](http://www.ip3d.fr/IP3D/SPIM/Entrees/2015/6/23_Print_it_Yourself_-_MultiSample_versatile_Holder_-_Print_all_you_need_with_a_3D_printer.html)  are pretty great.) I'll wait for his input and come back there on that.
####

Closed 2021-05-12.

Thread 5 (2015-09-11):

BUG: optical path in openscad is not up to date!

glyg, 2015-09-11:
The current path in openscad is not up to date.

In the instrument released in v. 0.1, the **collection lens** used to make the image is the  one that was designed for the **excitation** path, for LED collimation.

This need to be fixed quickly in openscad here:
https://github.com/glyg/mu_spim/blob/master/open_scad/excitation_optics.scad#L2

to make things clear:
The collection lens corresponds to [this thorlabs lens](http://www.thorlabs.de/thorproduct.cfm?partnumber=AC050-008-A-ML).

Closed 2021-05-12.

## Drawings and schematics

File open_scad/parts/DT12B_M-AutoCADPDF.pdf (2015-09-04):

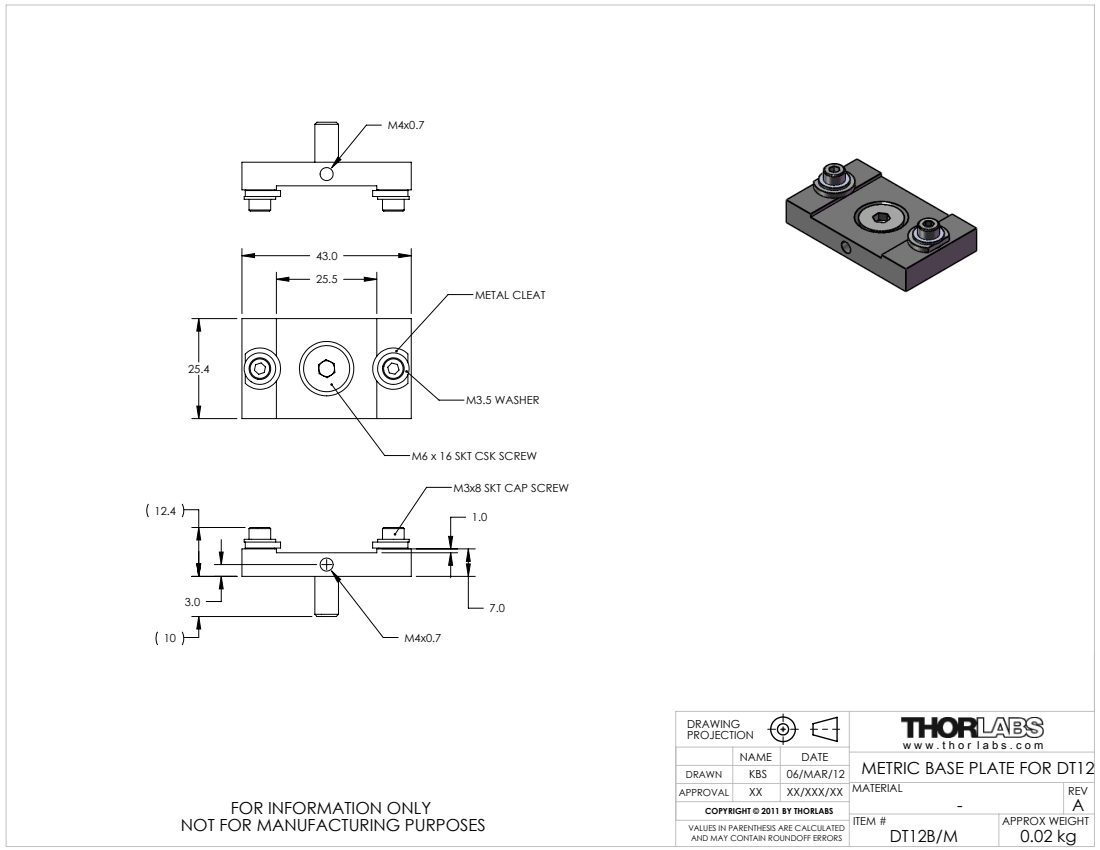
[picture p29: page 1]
METAL CLEAT; M3.5 WASHER; ITEM #; APPROX WEIGHT

M6 x 16 SKT CSK SCREW

M3x8 SKT CAP SCREW

DRAWING PROJECTION | | w w w . t h o r l a b s . c o m

NAME | DATE
APPROVAL | XX | XX/XXX/XX | MATERIAL - | REV A

METRIC BASE PLATE FOR DT12

DRAWN | KBS | 06/MAR/12

FOR INFORMATION ONLY
NOT FOR MANUFACTURING PURPOSES

COPYRIGHT © 2011 BY THORLABS
0.02 kg VALUES IN PARENTHESIS ARE CALCULATED
AND MAY CONTAIN ROUNDOFF ERRORS

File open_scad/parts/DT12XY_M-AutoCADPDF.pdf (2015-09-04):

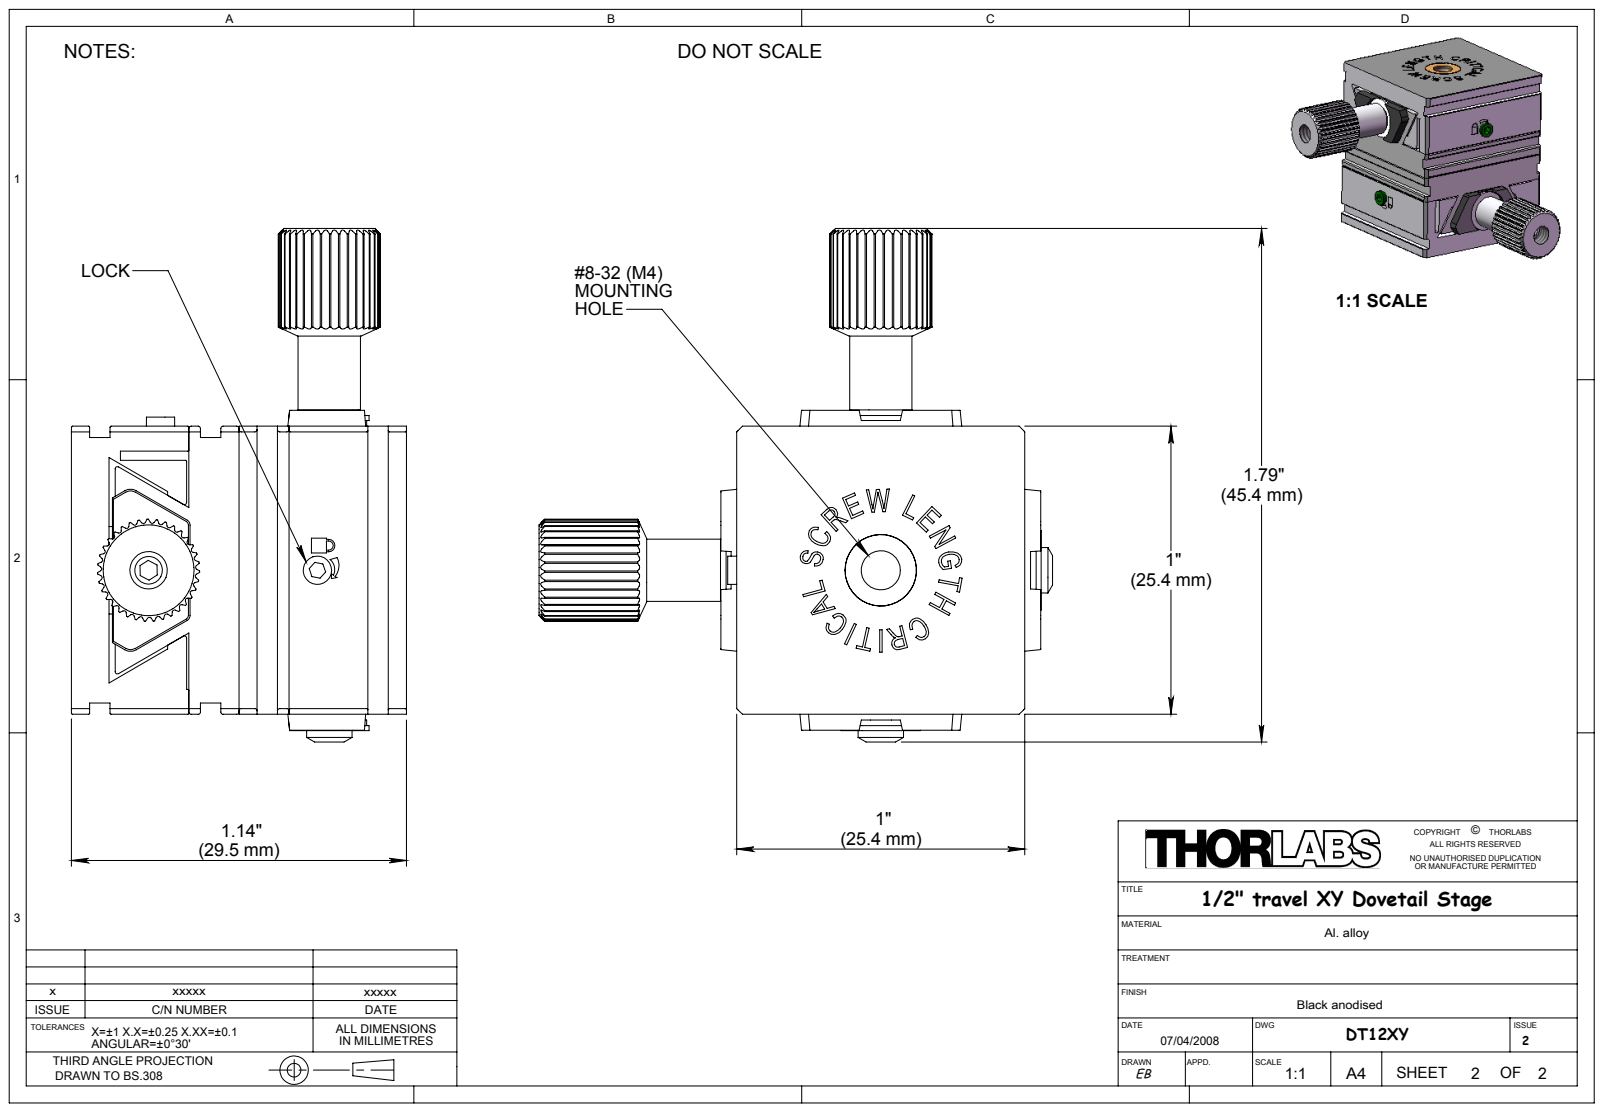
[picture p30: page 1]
1:1 SCALE; ALL DIMENSIONS IN MILLIMETRES; C/N NUMBER; NOTES:; DO NOT SCALE; Al. alloy; Black anodised

ALL RIGHTS RESERVED
NO UNAUTHORISED DUPLICATION
OR MANUFACTURE PERMITTED

TITLE
1/2" travel XY Dovetail Stage

ISSUE
TOLERANCES
THIRD ANGLE PROJECTION
DRAWN TO BS.308

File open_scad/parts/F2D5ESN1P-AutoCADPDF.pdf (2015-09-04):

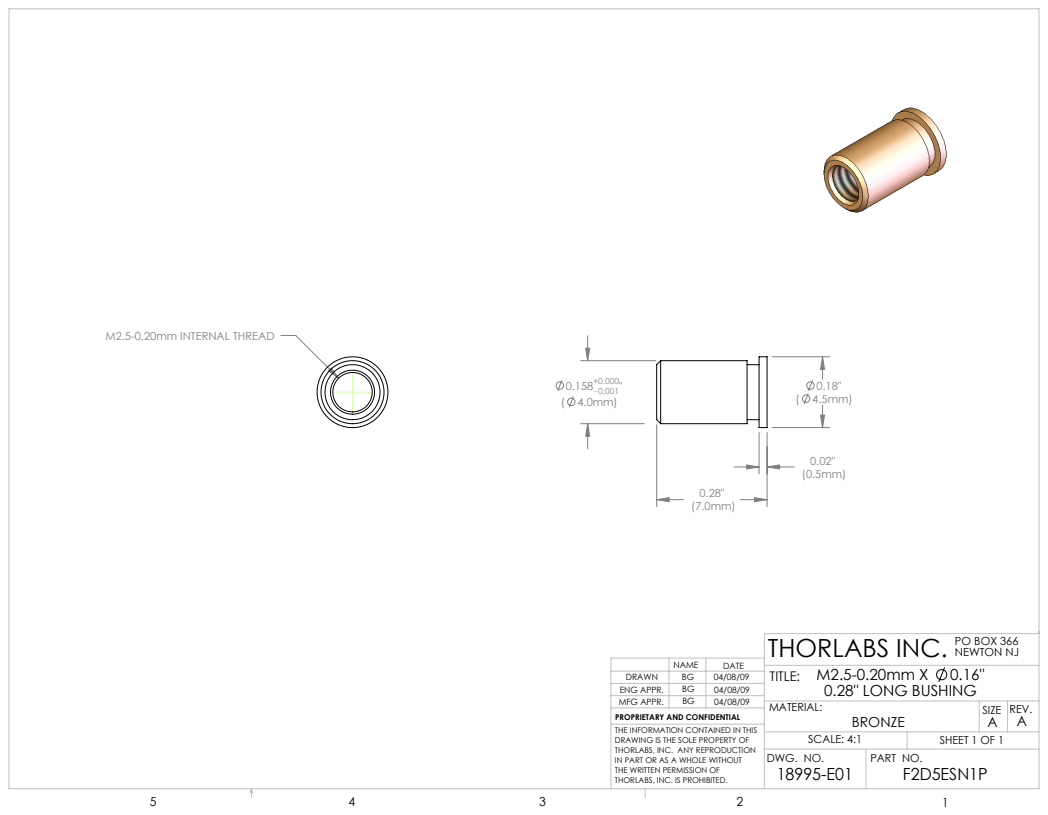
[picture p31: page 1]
M2.5-0.20mm INTERNAL THREAD; PART NO.; SCALE: 4:1; SHEET 1 OF 1; DWG. NO.; THORLABS INC. PO BOX 366 NEWTON NJ M2.5-0.20mm X 0.16" 0.28" LONG BUSHING

DRAWN
ENG APPR.
MFG APPR.
PROPRIETARY AND CONFIDENTIAL
THE INFORMATION CONTAINED IN THIS
DRAWING IS THE SOLE PROPERTY OF
THORLABS, INC. ANY REPRODUCTION
IN PART OR AS A WHOLE WITHOUT
THE WRITTEN PERMISSION OF
THORLABS, INC. IS PROHIBITED.

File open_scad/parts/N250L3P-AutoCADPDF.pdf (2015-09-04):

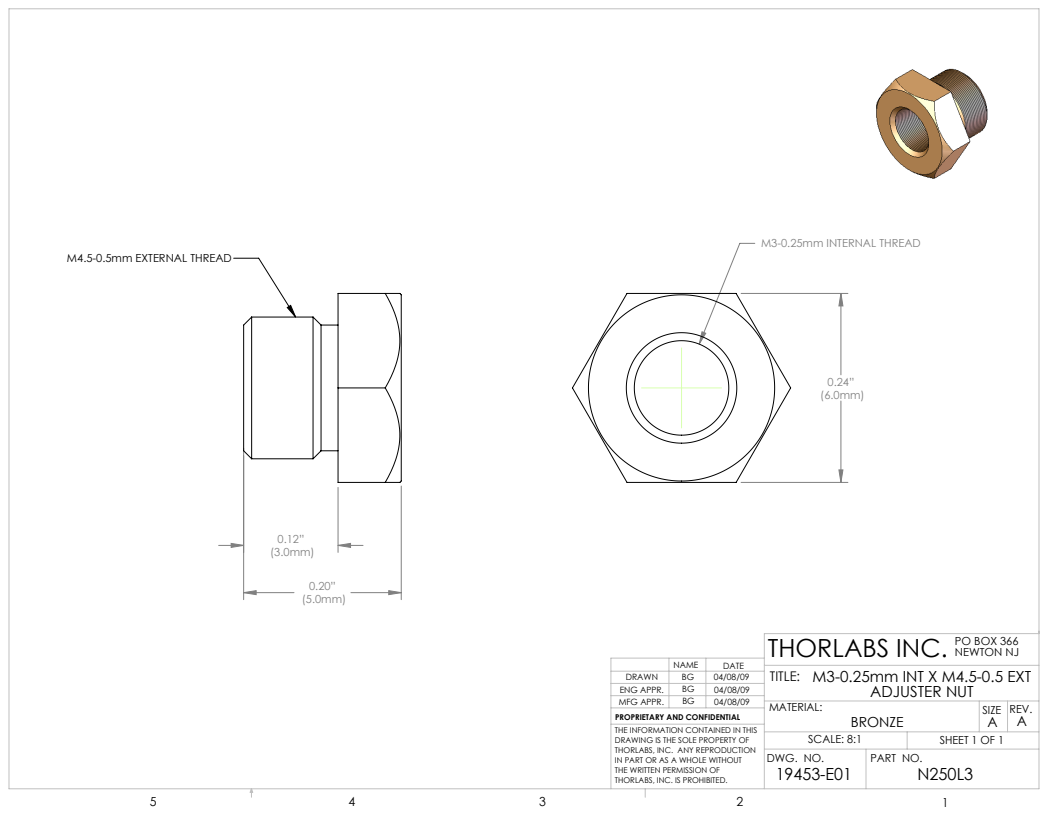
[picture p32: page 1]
M3-0.25mm INTERNAL THREAD; M4.5-0.5mm EXTERNAL THREAD; PART NO.; SCALE: 8:1; SHEET 1 OF 1; DWG. NO.; NEWTON NJ; ADJUSTER NUT

THORLABS INC. PO BOX 366
M3-0.25mm INT X M4.5-0.5 EXT
TITLE:

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

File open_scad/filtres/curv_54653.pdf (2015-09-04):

## OG 515 VIS Longpass Filter Coating Performance FOR REFERENCE ONLY

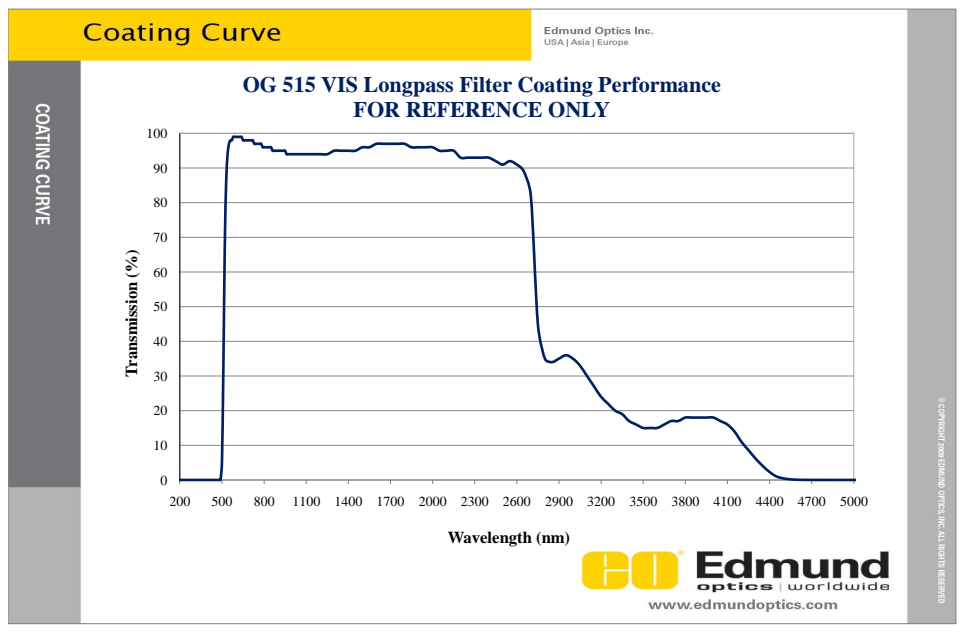
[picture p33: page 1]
Transmission (%); Wavelength (nm)

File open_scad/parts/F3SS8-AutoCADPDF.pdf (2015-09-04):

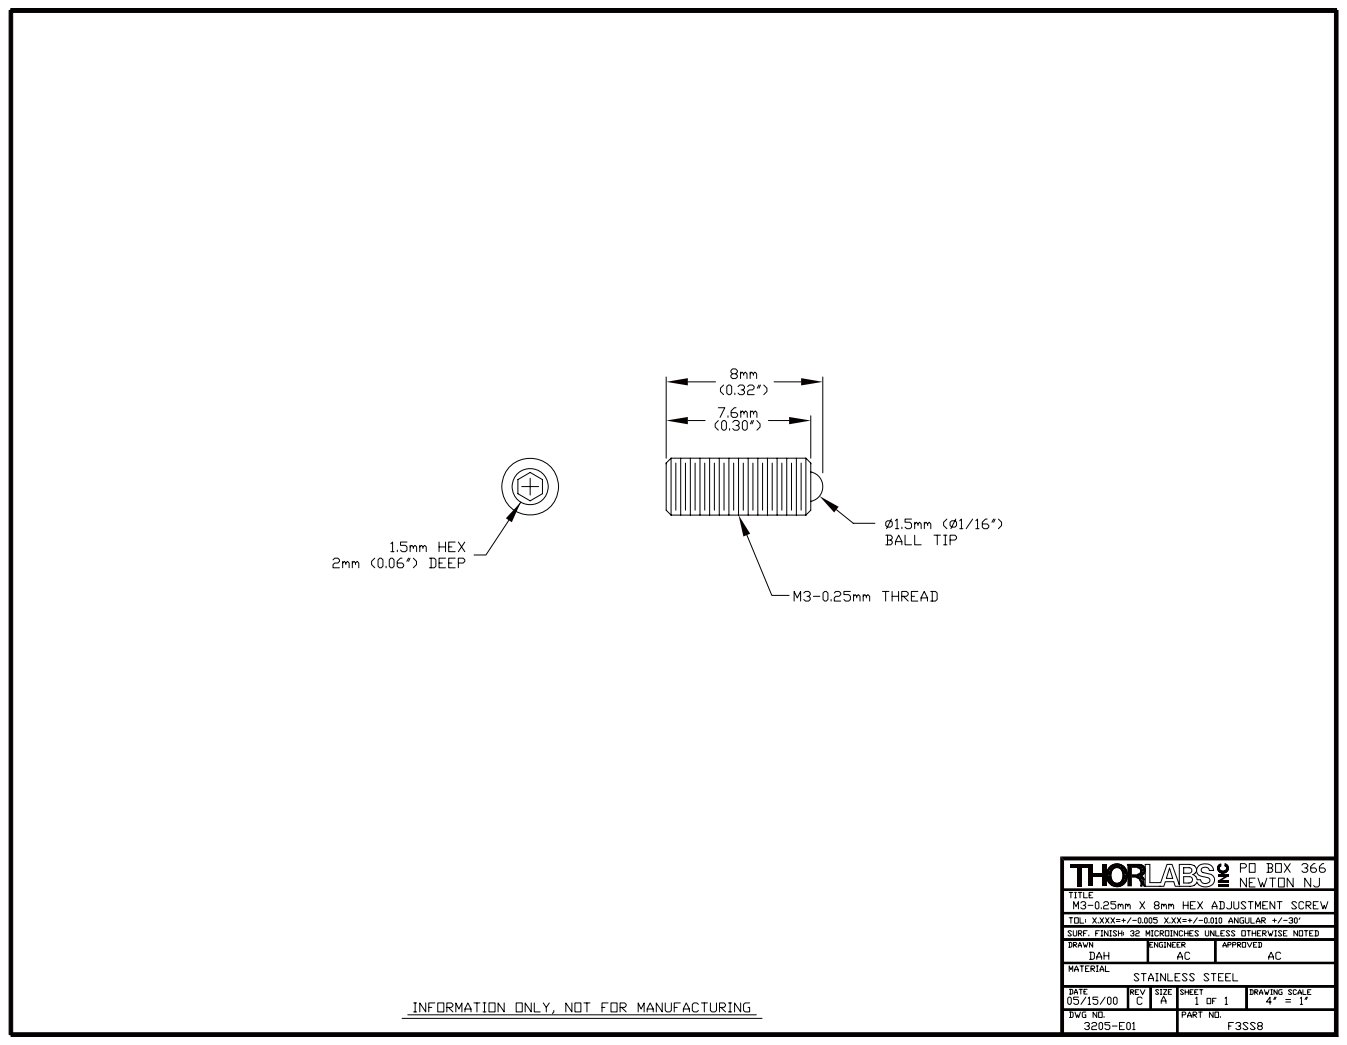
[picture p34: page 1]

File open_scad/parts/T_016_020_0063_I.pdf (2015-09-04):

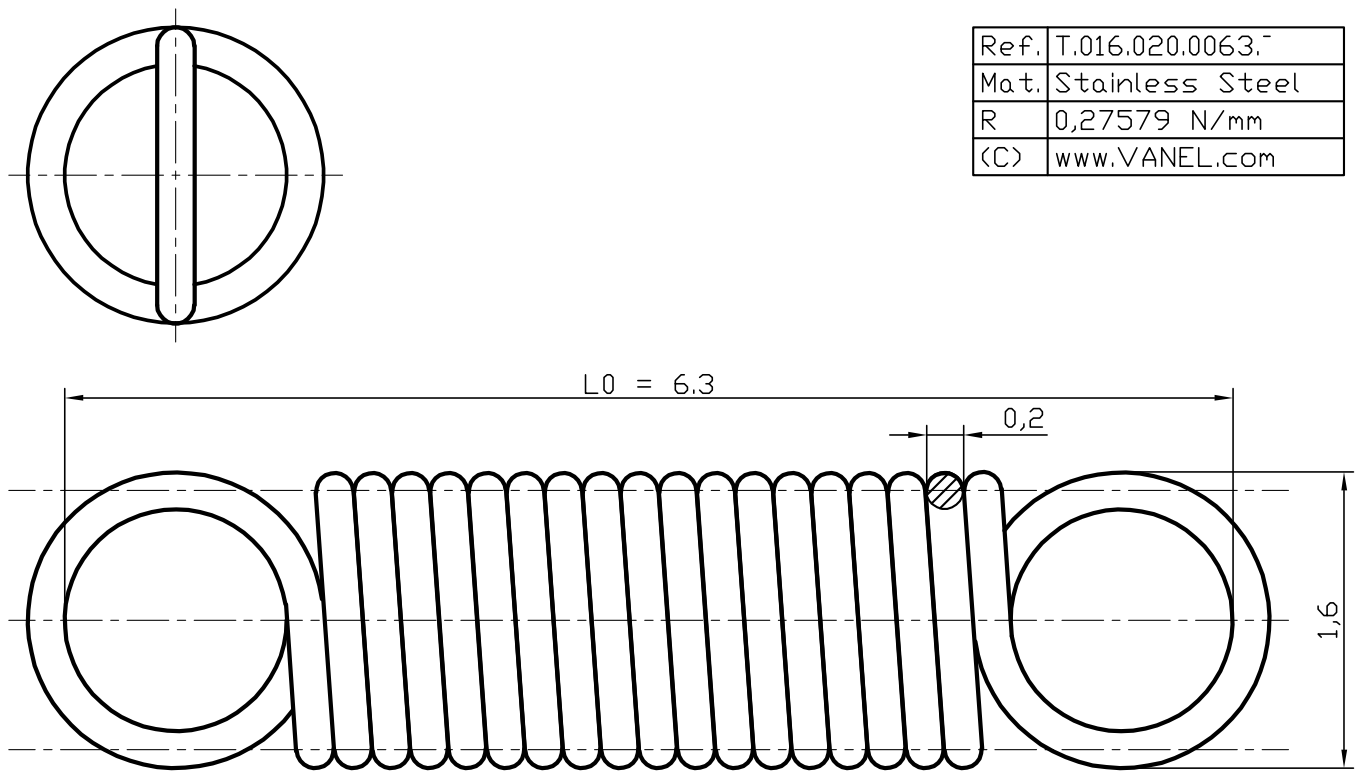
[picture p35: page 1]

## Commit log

2015-02-01 starting with optics
    [excitation_optics.scad, mu_spim.scad, phone.scad]
2015-02-06 added cyl.lens
    [excitation_optics.scad, mu_spim.scad, phone.scad]
2015-02-06 included collection lens
    [collection_optics.scad, mu_spim.scad]
2015-02-06 excitation filter
    [excitation_optics.scad, mu_spim.scad]
2015-02-21 added colors (whoaaa)
    [excitation_optics.scad, mu_spim.scad, phone.scad]
2015-02-23 added excitation light path
    [excitation_optics.scad, mu_spim.scad, phone.scad]
2015-03-14 small modif
    [mu_spim.scad]
2015-03-15 started work on sample chamber
    [chamber.scad, collection_optics.scad, light_path.scad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]
2015-03-16 Lots of new stuff - optics holding
    [chamber.scad, collection_optics.scad, mu_spim.scad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]
2015-03-17 progress on the base
    [base.scad, mu_spim.scad, optic_blocks.scad]
2015-04-02 phone foot
    [base.scad, mu_spim.scad]
2015-04-09 image outputs
    [mu_spim.scad]
2015-04-19 working on chassis
    [base.scad, sample_holder.scad]
2015-05-14 addapting to the new phone
    [base.scad, mu_spim.scad, optic_blocks.scad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]
2015-06-06 started to work on cnc adaptation
    [cnc_parts.scad, mu_spim.scad, optic_blocks.scad]
2015-07-17 WIP - export to STL
    [base_dimensions.scad, cnc_parts.scad, optic_blocks.scad]
2015-07-17 renamed cnc to stl
    [stl_parts.scad]
2015-07-17 exported to STL
    [base.scad, base_block.stl, base_dimensions.scad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]
2015-07-17 fixed STL
    [chamber_top.stl, mu_spim.scad, stl_parts.scad]
2015-09-04 Added gallery
    [base.scad, base_block.stl, base_dimensions.scad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]
2015-09-04 moved scad files about
    [base.scad, base_dimensions.scad, chamber.scad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]
2015-09-04 file sorting
    [AC050-008-A-ML-AutoCADDXF.dxf, AC050-008-A-ML-Step.step, F3SS8-AutoCADDXF.dxf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]
